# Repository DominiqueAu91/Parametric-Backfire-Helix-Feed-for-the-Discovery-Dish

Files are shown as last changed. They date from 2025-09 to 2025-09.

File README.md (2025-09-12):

# Parametric Backfire Helix Feed for the Discovery Dish

**Goal.** A fully parametric **backfire helical feed** (single-wire) for deep prime-focus dishes (e.g., the **Discovery Dish**), supporting **circular polarization** (LHCP/RHCP), printable scaffolding, and an annular reflector (“donut”) sized for backfire operation. The design is plug-and-play with **Digitelektro’s ecosystem** (see third_party folder) and my extension tube that houses an **LNA + bias-T** directly behind the reflector to minimize system noise figure.

## Background & motivation

This started as a **radio-astronomy feed** around **1420 MHz** to detect Milky Way H I line. It quickly became a **parametric OpenSCAD model** and **3D-printable hardware** designed to be **plug-and-play** with **Digitelektro’s Discovery Dish** ecosystem and with an **extension tube** that shelters the **LNA** (plus bias-T) **in the reflector’s shadow**. Goals: switch L/S bands in minutes, **minimize overall NF** (LNA at the feed), and keep a **mechanically & RF-robust** setup for experimentation.

## What this model does

- **Backfire helix** scaffold + **annular reflector (“donut”)** sized for backfire (default inner diameter ≈ **0.29·λ**).
- **Dish reflection flips circular polarization**; set feed LH/RH accordingly (feed LHCP → sky RHCP, and vice-versa).
- **Parametric OpenSCAD**: frequency, turns, pitch angle (default **14°**), handedness, donut diameters, and vertical stiffening gussets.
- **Helix channel preview** (red) mirrors the subtracted volume for easy wire routing during assembly.

## Quick theory

- λ = c / f
- Circumference C ≈ k·λ (use k ≈ 1 for backfire) → D = k·λ / π
- Pitch per turn from pitch angle α:  
  p = π·D·tan(α)  (default α = 14°)
- Donut inner diameter ≈ 0.29·λ

## Key OpenSCAD parameters

- `freq_MHz`, `turns`, `pitch_angle_deg` (14° default), `circ_factor_k` (1.00 default)
- `helix_right_handed` (`true` / `false`). Remember: **dishes flip circular polarization**.
- `reflector_inner_factor` (0.29 default → donut inner ≈ 0.29·λ)
- `reflector_outer_d_mm` or `reflector_outer_factor` for outer diameter
- `support_inset_mm` to make the posts bite inside the helix radius
- Gussets: vertical plates, flat top / sloped bottom; join at center (`gusset_*`)

## Presets

See **BANDS.md** for L/S-band presets (H I + Radio-astro, GNSS, HRIT/HRPT, TT&C, 13 cm Amateur, Globalstar).

## How many turns? (illumination vs f/D)

The optimal number of helix turns depends on the dish focal ratio (f/D).  
A dish with smaller f/D (deeper dish) requires a **wider beam** (fewer turns).  
A dish with larger f/D (shallower dish) requires a **narrower beam** (more turns).

### Practical rule
- Dish edge angle from focus:  
  `θ_edge = arctan(0.5 / (f/D))`  
- Choose the helix length (number of turns × pitch) so that the **pattern taper at θ_edge** is about **–10 to –13 dB**.  
  This balances aperture efficiency and noise contribution.

### Typical values (backfire helix, D ≈ λ, pitch angle ≈ 14°)
- f/D ≈ 0.30 → 3.5–4 turns  
- f/D ≈ 0.35 → ~3.0 turns (Discovery Dish)  
- f/D ≈ 0.40 → 2.8–3.2 turns  
- f/D ≈ 0.45–0.50 → 2.5–3 turns

### Hydrogen line example
At 1420.42 MHz (`λ ≈ 211 mm`):  
- Helix diameter `≈ 67.2 mm`  
- Pitch per turn `≈ 52.6 mm`  
- For f/D = 0.35 → **3.0 turns** → helix height ≈ 158 mm  
- Donut inner diameter ≈ `0.29·λ ≈ 61 mm`  

This setting gives a clean illumination of the dish, with proper edge taper for low-noise radio astronomy work.

### Choosing the number of turns based on your noise environment

The “optimal” number of turns is not only a function of dish f/D, but also of your RF environment:

- **Quiet rural site:**  
  Use **~3 turns**. The dish edge is illuminated at about –10 dB, which maximizes aperture efficiency.  
  Ground spillover is low in quiet sites, so you benefit from the extra effective aperture.

- **Urban or noisy suburban site:**  
  Consider **5–7 turns**. The beam narrows and under-illuminates the dish (edge taper ≈ –15 to –18 dB).  
  Although efficiency drops slightly, spillover from the ground and local RFI is strongly reduced.  
  The effective system noise temperature is lower, so overall SNR can actually improve.

👉 Rule of thumb:  
- For **radio astronomy, HRPT, or weak-signal work in rural areas** → ~3 turns.  
- For **general SDR satellite reception in noisy areas** → 5–7 turns.

## Matching (¼-wave transformer)

Typical backfire single-wire helix impedance: `Z_feed ≈ 120–150 Ω`.  
Use a **quarter-wave transformer** with characteristic impedance: Z_t = √(50 · Z_feed)

Example: if `Z_feed = 125 Ω` → `Z_t ≈ 79 Ω`.  

Implement with a λ/4 section of coax, twin-line, or microstrip near the feed point.  
Fine-tune by trimming the first fraction of a turn.  

## Printing & assembly

PETG ~20% infill; use the red helix preview to pre-check the wire path. Put the LNA right behind the reflector (shadowed), bias-T at the SDR. Keep unintended metal away from the donut edge; **0.29·λ** inner diameter is RF-critical.
## Additional Files and Quick Start

Alongside the parametric OpenSCAD sources, two key design files are provided:

- **`tripod_helix_donut.scad`**  
  Parametric model of the backfire helix feed support with tripod posts, gussets, and donut base.  
  Fully customizable: frequency, reflector diameter, number of turns, pitch angle, etc.  
  Designed to generate a mechanically robust feed suitable for use at the focal point of the Discovery Dish or other parabolic reflectors.

- **`para_extension_tube_inserts_M3.scad`**  
  Parametric design of the extension tube adapter.  
  This tube fits between **Digitelektro’s backfire_helix_adapter_for_discovery_dish** (see third_party folder) and the backfire helix feed.  
  Its purpose is to house and protect an LNA (e.g. **SPF5189Z**), filter (e.g. **Mini-Circuits VHF 1200+**) and a Bias-T immediately behind the helix reflector, in the geometric shadow of the reflector.  
  It supports Ruthex threaded inserts (M3 or M4), making it easy to switch between different feeds (L-band and S-band) while maintaining strong mechanical stability.

### Pre-generated STL Files

For convenience, **STL files are provided for the 1420.42 MHz hydrogen line (H I radio astronomy)** configuration.  
These can be directly printed — PETG recommended, ≥20% infill — to assemble a ready-to-use feed for neutral hydrogen observations.

### Quick Start

1. If your goal is **1420 MHz radio astronomy (hydrogen line)**:  
   - Print the supplied STL files directly.  
   - Mount the backfire helix feed on your Discovery Dish using the extension tube.  
   - Insert your LNA + Bias-T inside the tube.

2. If you want to explore **other bands**:  
   - Open `tripod_helix_donut.scad` in OpenSCAD.  
   - Adjust parameters (frequency, turns, reflector diameter, polarization).  
   - Export your own STL for printing.  
   - Optional: use `para_extension_tube_inserts_M3.scad` if you need the protected LNA/Bias-T housing.

This makes the project **plug-and-play** for hydrogen line observations while still giving full flexibility for other L-band and S-band satellite experiments.
## Generating Gerber Files for Your Custom Reflector Disk

This project includes a KiCad 8 **action plugin** (`donut_reflector_disk_sma.py`) to generate a parametric round reflector PCB with:

- **Circular Edge.Cuts outline**  
- **Ground planes (F.Cu & B.Cu)** tied to the SMA ground pins  
- **Optional soldermask opening** (bare copper reflector)  
- **Centered "China 6x6 inner 4mm" or "CONSMA001-C-G" SMA footprint** (square or round GND pads)  
- **Custom silkscreen label**

### Steps to Generate Gerbers

1. **Run the plugin**  
   - In KiCad PCB Editor:  
     `Tools → External Plugins → Parametric Reflector Disk + SMA`  
   - Enter:
     - Frequency in MHz (auto-calculates reflector diameter = 0.29·λ)  
     - Custom silkscreen label  
     - Option: open soldermask (bare copper)  

2. **Verify in PCB Editor**  
   - Confirm the reflector disk outline is present.  
   - Ensure the copper zones fill properly and connect to the SMA ground pins.  
   - Use the **Highlight Net** tool: selecting any SMA ground pin should highlight the whole disk.

3. **Generate Gerbers**  
   - Go to: `File → Plot…`  
   - Choose **Gerber** format.  
   - Enable at least these layers:
     - `F.Cu`, `B.Cu`  
     - `F.Mask`, `B.Mask`  
     - `F.SilkS` (optional, for label)  
     - `Edge.Cuts` (always required)  
   - Click **Plot**.

4. **Generate Drill Files**  
   - In the same dialog, click **Generate Drill Files…**  
   - Select **Excellon format** and include **PTH drills**.  
   - Click **Generate Drill File**.

5. **Check with Gerber Viewer**  
   - Open the output in KiCad’s **GerbView**.  
   - Confirm:
     - Copper fills are present on both sides.  
     - Mask opening (if enabled) exposes the reflector area.  
     - Drill holes are correct for the SMA center pin and ground legs.  

6. **Prepare for Fabrication**  
   - Zip the Gerber and drill files.  
   - Upload to your fab (e.g., JLCPCB).  
   - Recommended JLCPCB options:
     - Material: FR-4, 1.6 mm  
     - Copper: 1 oz  
     - Surface finish: ENIG (1U")  
     - Soldermask: Black (or your choice)  
     - Silkscreen: White  

---

👉 With this workflow you can generate **custom reflector disks** for any band (L-band, S-band, hydrogen line at 1420 MHz, etc.) simply by entering the frequency in the plugin dialog.

## Licensing & credits

- This repo (OpenSCAD + plugin + docs): **CC0**
- Digitelektro / BackfireHelix: **GPL-3.0** — keep attribution & GPL if you reuse their PCB files.
- Classic backfire references: **Nakano & Yamauchi (IEEE)**, **W1GHZ**, **N1BWT** notes.

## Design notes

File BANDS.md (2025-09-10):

# Bands & presets (k = 1.00, pitch angle = 14°)
| Target band | f (MHz) | λ (mm) | Helix D (mm) | Pitch/turn (mm) | Donut inner ≈ 0.29·λ (mm) |
|---|---:|---:|---:|---:|---:|
| H I line | 1420.42 | 211.1 | 67.2 | 52.6 | 61.2 |
| Radio-astro L | 1520.00 | 197.37 | 62.82 | 49.21 | 57.24 |
| GNSS L1 | 1575.42 | 190.43 | 60.61 | 47.48 | 55.22 |
| HRIT/HRPT | 1694.10 | 177.09 | 56.37 | 44.15 | 51.35 |
| TT&C S-band | 2200.00 | 136.36 | 43.41 | 33.99 | 39.55 |
| Amateur 13 cm | 2400.00 | 125.00 | 39.79 | 31.17 | 36.25 |
| Globalstar downlink | 2484.00 | 120.77 | 38.44 | 30.11 | 35.02 |

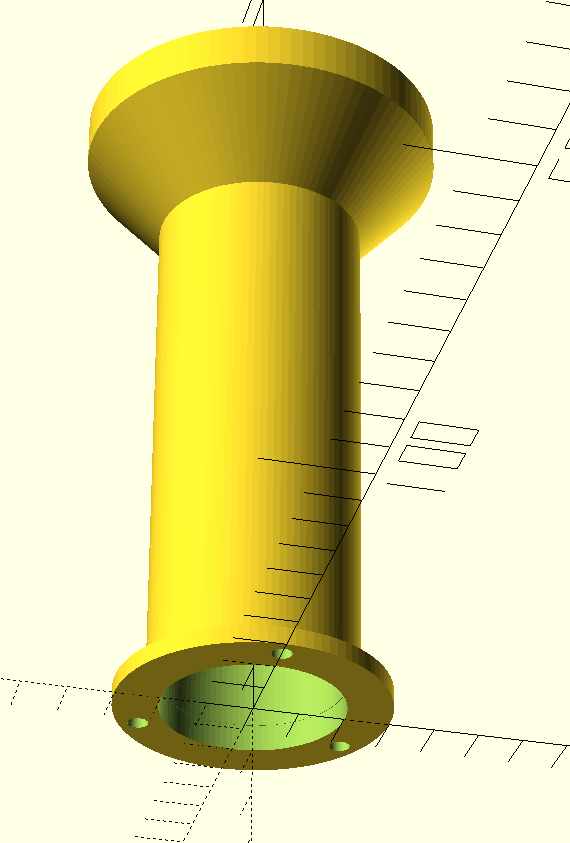
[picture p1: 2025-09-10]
Images/extension_tube_insert_1420.PNG

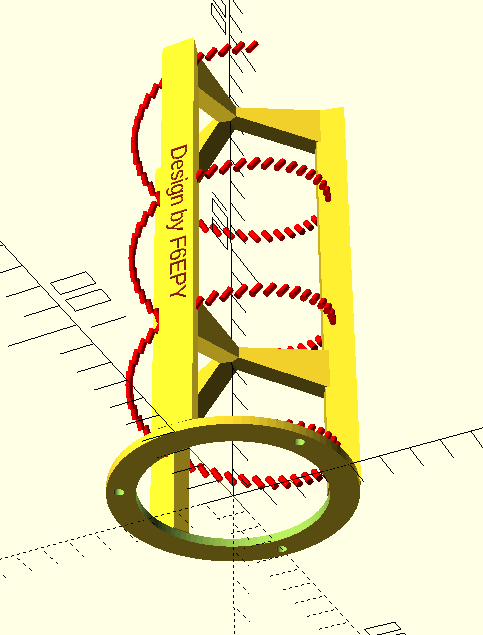
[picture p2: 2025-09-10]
Images/Backfire Helix.PNG

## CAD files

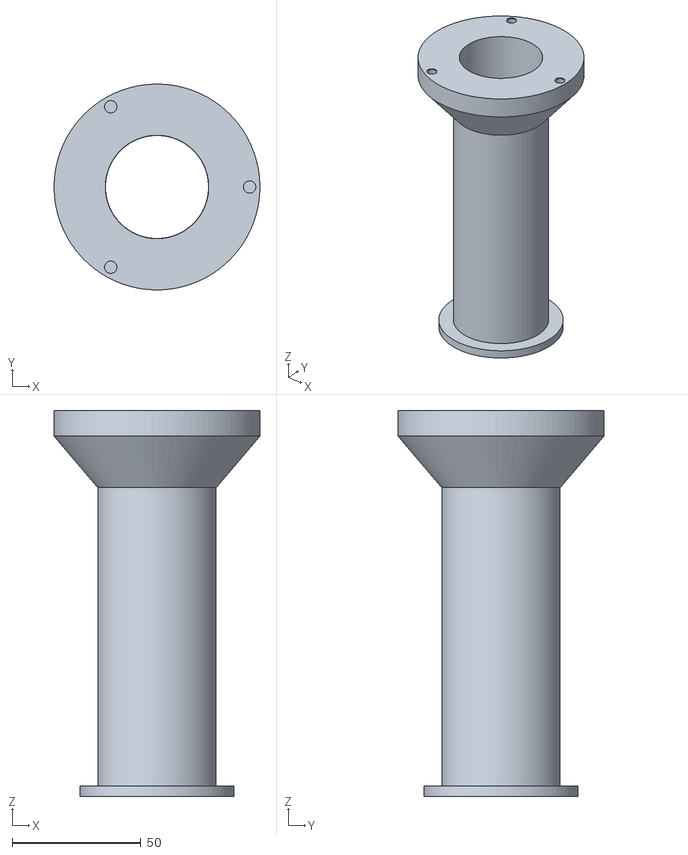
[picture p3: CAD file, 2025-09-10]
STL files/extension_tube_insert_M3_1420.stl
80.0 x 80.0 x 150.0

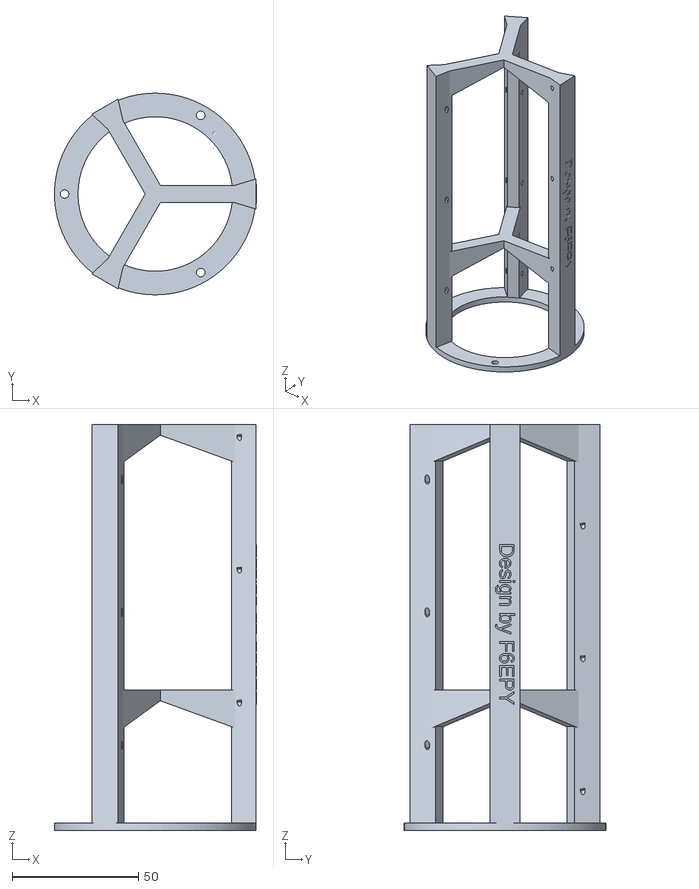
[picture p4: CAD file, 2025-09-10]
STL files/tripod_helix_donut_1420_H_I.stl
80.2 x 80.0 x 161.0

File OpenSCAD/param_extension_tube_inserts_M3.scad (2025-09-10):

//
// Parametric extension tube between Digitelektro's "Discovery Dish helix adapter"
// and "Backfire helix feed" to fit an LNA + Bias-T.
// Flange B: heat-set inserts ONLY (select M3 or M4). Clean & printable.
// Author: Cooperation between ChatGPT and Dominique F6EPY
// License: CC0

$fn = 96;

// ------------------------- User Parameters -------------------------

// Core tube
length_mm        = 120;   // extension length
id_mm            = 40;   // inner diameter
wall_mm          = 3;    // wall thickness
center_hole_A_d  = 40;   // central through-hole on flange A (Discovery side)
center_hole_B_d  = 40;   // central through-hole on flange B (Backfire side)
bevel_mm         = 0.6;  // small bevel on tube edges

// Flanges (A = Discovery side, B = Backfire side)
flangeA = [
  "thickness",   4,
  "outer_d",     60,
  "hole_count",  3,
  "bcd",         51.5,
  "hole_d",      4.5,   // A-side through holes
  "angle0_deg",  0,
  // optional features (set 0 to disable)
  "cbore_d",     7.5, "cbore_depth", 1.5,   // counterbore on OUTER face
  "boss_d",      42,  "boss_h",       1.0,  // boss (male) on INNER face
  "recess_d",     0,  "recess_h",     0     // recess (female) on INNER face
];

flangeB = [
  "thickness",   30,   // thicker, typically the tapered one
  "outer_d",     80,
  "hole_count",  3,
  "bcd",         72.0,
  "hole_d",      3.2,  // unused now (kept for compatibility)
  "angle0_deg",  0,
  // optional features
  "cbore_d",     0,   "cbore_depth", 0,
  "boss_d",      0,   "boss_h",      0,
  "recess_d",    42,  "recess_h",    1.0
];

// ---- Inserts on flange B ----
// Choose size M3/M4 (defaults below) OR override custom values
insert_size         = "M3";   // "M3" | "M4"
insert_override     = false;  // true -> use custom values below (ignoring size defaults)
insert_d_outer_M3   = 4.8;    // typical pocket Ø for Ruthex M3 in PLA/PETG
insert_len_M3       = 5.0;    // pocket depth for M3
insert_d_outer_M4   = 5.6;    // typical pocket Ø for Ruthex M4 in PLA/PETG
insert_len_M4       = 9.0;    // pocket depth for M4
insertB_d_outer     = 6.0;    // custom pocket Ø if override=true
insertB_length      = 6.0;    // custom pocket depth if override=true
insertB_chamfer     = 0.4;    // small entry chamfer height (mm)

// Taper setup — applies to ONE side only (kept as before)
tapered_flange     = "B";   // "A" or "B"
taper_enabled      = true;  // set false to disable taper entirely
big_at_outer       = true;  // true: big OD at OUTER face; false: big OD at INNER face
taper_flat_side    = "big"; // keep a flat at "big" or "small" OD side
taper_flat_h       = 10;    // default flat height (mm)
taper_flat_B_h     = 10;    // specific flat height for flange B (overrides default)

// ------------------------- Helpers -------------------------

function kv(h, k, default_val=0) =
    let (idx = search([k], [for(i=[0:len(h)/2-1]) h[2*i]]))
    (len(idx) > 0) ? h[2*idx[0]+1] : default_val;

function is_tapered(which) =
    (taper_enabled && ((tapered_flange == "A" && which=="A") || (tapered_flange == "B" && which=="B")));

function ins_d_default(size) = (size=="M3") ? insert_d_outer_M3 : insert_d_outer_M4;
function ins_h_default(size) = (size=="M3") ? insert_len_M3     : insert_len_M4;

module bevel_ring(id, od, h) {
  difference() {
    cylinder(h=h, d=od, center=false);
    translate([0,0,-0.01]) cylinder(h=h+0.02, d=id, center=false);
  }
}

module cbore(d, depth) { translate([0,0,-depth]) cylinder(h=depth, d=d, center=false); }

// ------------------------- Main geometry -------------------------

module adapter_tube() {
  tube_od = id_mm + 2*wall_mm;

  union() {
    // Tube
    difference() {
      cylinder(h=length_mm, d=tube_od, center=false);
      translate([0,0,-0.01]) cylinder(h=length_mm+0.02, d=id_mm, center=false);
    }
    if (bevel_mm > 0) {
      translate([0,0,0]) bevel_ring(id_mm, tube_od, bevel_mm);
      translate([0,0,length_mm]) rotate([180,0,0]) bevel_ring(id_mm, tube_od, bevel_mm);
    }

    // Flanges
    translate([0,0,0])         flange_end(flangeA, "A");           // inner face at Z=0
    translate([0,0,length_mm]) flange_end(flangeB, "B");           // inner face at Z=0 of this module
  }
}

module flange_end(params, which="A") {
  tube_od   = id_mm + 2*wall_mm;

  th        = kv(params,"thickness",4);
  od        = kv(params,"outer_d", tube_od + 10);
  hole_cnt  = kv(params,"hole_count",0);
  bcd       = kv(params,"bcd",0);
  hole_d    = kv(params,"hole_d",3.2);
  angle0    = kv(params,"angle0_deg",0);

  cbore_d     = kv(params,"cbore_d",0);
  cbore_depth = kv(params,"cbore_depth",0);
  boss_d      = kv(params,"boss_d",0);
  boss_h      = kv(params,"boss_h",0);
  recess_d    = kv(params,"recess_d",0);
  recess_h    = kv(params,"recess_h",0);

  // Resolve insert dimensions by size/override (used only if which=="B")
  ins_d  = insert_override ? insertB_d_outer : ins_d_default(insert_size);
  ins_h  = insert_override ? insertB_length  : ins_h_default(insert_size);

  difference() {
    // ---- BODY (core + outer skin) ----
    union() {
      // Core: keeps inner bore unchanged
      cylinder(h=th, d=tube_od, center=false);

      if (is_tapered(which)) {
        flat_h = min((which=="B" ? taper_flat_B_h : taper_flat_h), th);

        // Inner face is Z=0, outer face is Z=th.
        big_at_z   = big_at_outer ? th : 0;   // where OD = od
        small_at_z = big_at_outer ? 0  : th;  // where OD = tube_od

        if (taper_flat_side == "big") {
          if (big_at_z == 0) {
            // Flat z=0..flat_h at OD=od
            difference() {
              cylinder(h=flat_h, d=od, center=false);
              translate([0,0,-0.01]) cylinder(h=flat_h+0.02, d=tube_od, center=false);
            }
            if (th > flat_h) translate([0,0,flat_h]) difference() {
              cylinder(h=th-flat_h, d1=od, d2=tube_od, center=false);
              translate([0,0,-0.01]) cylinder(h=th-flat_h+0.02, d=tube_od, center=false);
            }
          } else {
            if (th > flat_h) difference() {
              cylinder(h=th-flat_h, d1=tube_od, d2=od, center=false);
              translate([0,0,-0.01]) cylinder(h=th-flat_h+0.02, d=tube_od, center=false);
            }
            translate([0,0,th-flat_h]) difference() {
              cylinder(h=flat_h, d=od, center=false);
              translate([0,0,-0.01]) cylinder(h=flat_h+0.02, d=tube_od, center=false);
            }
          }
        } else { // flat on "small" side
          if (small_at_z == 0) {
            if (th > flat_h) translate([0,0,flat_h]) difference() {
              cylinder(h=th-flat_h, d1=tube_od, d2=od, center=false);
              translate([0,0,-0.01]) cylinder(h=th-flat_h+0.02, d=tube_od, center=false);
            }
          } else {
            if (th > flat_h) difference() {
              cylinder(h=th-flat_h, d1=od, d2=tube_od, center=false);
              translate([0,0,-0.01]) cylinder(h=th-flat_h+0.02, d=tube_od, center=false);
            }
            // top flat implicit by core
          }
        }
      } else {
        // Non-tapered outer cylinder at OD + tiny shoulder to tube OD
        cylinder(h=th, d=od, center=false);
        shoulder_h = max(0.01, min(1.2, th*0.25));
        cylinder(h=shoulder_h, d=tube_od, center=false);
      }
    }

    // ---- SUBTRACTIONS ----

    // Flange A: bolt circle (traversant classique)
    if (which=="A" && hole_cnt > 0 && bcd > 0) {
      for (i=[0:hole_cnt-1]) {
        ang = angle0 + 360*i/hole_cnt;
        px = (bcd/2)*cos(ang);
        py = (bcd/2)*sin(ang);
        translate([px, py, 0]) cylinder(h=th+0.4, d=hole_d, center=false);
      }
    }

    // Flange B: inserts (M3/M4) — blind pockets on OUTER flat
    if (which=="B" && hole_cnt > 0 && bcd > 0) {
      depth = min(ins_h, th-0.4);
      for (i=[0:hole_cnt-1]) {
        ang = angle0 + 360*i/hole_cnt;
        px = (bcd/2)*cos(ang);
        py = (bcd/2)*sin(ang);
        if (depth > 0) {
          translate([px, py, th - depth]) cylinder(h=depth+0.2, d=ins_d, center=false);
          if (insertB_chamfer > 0 && insertB_chamfer < depth)
            translate([px, py, th - insertB_chamfer])
              cylinder(h=insertB_chamfer+0.2, d1=ins_d+0.6, d2=ins_d, center=false);
        }
      }
    }

    // Central through-hole (per flange)
    chd = (which=="A") ? center_hole_A_d : center_hole_B_d;
    translate([0,0,-1]) cylinder(h=th+2, d=chd, center=false);
    translate([0,0,-1]) cylinder(h=th+2, d=chd+0.2, center=false);

    // Female recess on inner face (optional)
    if (recess_d > 0 && recess_h > 0)
      translate([0,0,0]) cylinder(h=recess_h, d=recess_d, center=false);
  }
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

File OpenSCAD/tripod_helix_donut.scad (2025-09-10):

//
// Backfire Helix Tripod + Donut (parametric)
// - Donut: inner = 0.29·λ by default (backfire), outer set by factor or mm
// - Helix: pitch angle (default 14°), C = k·λ, RH/LH handedness
// - Vertical gussets: flat top, sloped bottom; join at center; printable slopes
// - Subtractive helix channel + (optional) red preview
// Author: Dominique F6EPY + ChatGPT — CC0
//

// --- engraving config ---
engrave_enable            = true;
engrave_text              = "Design by F6EPY";
engrave_support_angle     = 0;       // 0 / 120 / 240
engrave_size_mm           = 6;
engrave_depth_mm          = 1.8;     // must be > face_gap
engrave_pos_frac          = 0.50;    // 0..1 along height
engrave_face_gap          = 0.15;    // small air gap before wall
engrave_use_tangential    = false;   // true = side (+/-Y), false = radial (+/-X)
engrave_outer_face        = true;    // tangential: +Y outer / radial: +X outer(back)
engrave_y_frac            = 0.0;     // -0.5..+0.5 across width (radial mode)
engrave_text_rot_deg      = 0;       // rotate text on face
engrave_debug_cube        = false;    // notch first to verify
engrave_overlay_show      = true;    // draw red overlay (F5) if desired
engrave_flip_horizontal = true;   // flip text horizontally to correct mirroring


// --- preview controls ---
preview_mode        = 2;     // 0=subtractive, 1=transparent overlay, 2=subtractive+red-peek, 3=cutaway
structure_alpha     = 0.35;  // transparency for overlay mode (mode 1)
preview_expand_mm   = 0.30;  // extra radius for red preview (mode 2)

// Cutaway settings (mode 3)
cutaway_axis        = "X";   // "X","Y","Z"
cutaway_offset_mm   = 0;     // shift cut plane along axis
cutaway_keep_positive = true;// keep +axis side (true) or –axis side (false)

// ---------- Quality / robustness ----------
$fn_solid   = 96;    // donuts/supports/gussets
$fn_channel = 28;    // helix channel cylinders (keep lower)
eps_z       = 0.02;  // tiny Z nudge to avoid coplanar faces

// ---------- RF & helix ----------
freq_MHz           = 1420;
turns              = 3.0;
circ_factor_k      = 1.00;   // C = k*lambda (≈1 for backfire)
pitch_angle_deg    = 14;     // degrees (OpenSCAD trig uses degrees)
helix_right_handed = true;   // true = RH, false = LH
helix_phase0_deg   = 45;

// ---------- Donut (annular reflector) ----------
reflector_inner_factor = 0.29; // inner ≈ 0.29*lambda
reflector_outer_d_mm   = 80;    // if 0 => use factor below
reflector_outer_factor = 0.90; // outer ≈ 0.90*lambda when outer_d_mm==0
base_thick             = 3;

// ---------- Bolt circle (optional) ----------
bolt_hole_count   = 3;
bolt_circle_d     = 72;
bolt_hole_d       = 3.5;
bolt_angle0_deg   = 60;

// ---------- Supports (trapezoids) ----------
support_inset_mm     = 3.5;  // posts bite inside helix radius
support_w_outer      = 12;   // tangential width near donut
support_w_inner      = 6;    // tangential width near center
support_outer_margin = 0;    // setback from donut outer radius

// ---------- Vertical gussets (radial planes) ----------
gusset_enable        = true;
gusset_top_h         = 0;   // flat top height above donut
gusset_center_thick  = 3.5;  // vertical thickness at center (min)
gusset_post_thick    = 15.0;  // vertical thickness at support (target)
gusset_angle_max_deg = 45;   // max printable slope (degrees)
gusset_embed_rad     = 1.5;  // radial embed into support
gusset_min_tan       = 2.8;  // min tangential extrusion width
levels_per_rev       = 2.0;    // gusset rings per full turn (>=1)
show_gusset_debug    = false;

// ---------- Helix channel (subtractive) + preview ----------
wire_d             = 1.4;
wire_clearance     = 0.6;
helix_step_deg     = 8;      // 6..10 typical; larger = lighter
show_helix_preview = true;
helix_preview_alpha= 1.0;
helix_preview_d    = 0;      // 0 => same as channel_d

// ---------- Debug ----------
show_axis          = false;

// ---------- Helpers ----------
function clamp(x,a,b) = (x < a) ? a : ((x > b) ? b : x);

// ---------- Derived ----------
lambda  = 300.0 / (freq_MHz/1000.0);
circum  = circ_factor_k * lambda;
helix_D = circum / PI;
helix_R = helix_D/2;
pitch   = PI * helix_D * tan(pitch_angle_deg);  // degrees OK in OpenSCAD
H_total = turns * pitch;

reflector_ir = (reflector_inner_factor * lambda) / 2;
reflector_or = (reflector_outer_d_mm > 0) ? (reflector_outer_d_mm/2)
                                          : ((reflector_outer_factor*lambda)/2);

// global radii for supports/gussets
post_inner_r = max(helix_R - support_inset_mm, 0.1);
post_outer_r = max(reflector_ir + 3, reflector_or - support_outer_margin);

// tangential width of support vs radius (linear interpolation)
function support_width_at(r) =
    (abs(post_outer_r - post_inner_r) < 1e-6)
    ? support_w_inner
    : let(t = clamp((r - post_inner_r) / (post_outer_r - post_inner_r), 0, 1))
      support_w_inner + t * (support_w_outer - support_w_inner);

// ---------- Modules ----------
module axis(len=80){
  color("red")   cube([len,0.8,0.8], center=true);
  color("green") cube([0.8,len,0.8], center=true);
  color("blue")  cube([0.8,0.8,len], center=true);
}

module reflector_donut(){
  difference(){
    cylinder(h=base_thick, r=reflector_or, center=false, $fn=$fn_solid);
    translate([0,0,-0.1])
      cylinder(h=base_thick+0.2, r=reflector_ir, center=false, $fn=$fn_solid);
    if (bolt_hole_count>0 && bolt_circle_d>0){
      for (i=[0:bolt_hole_count-1]){
        ang = bolt_angle0_deg + 360*i/bolt_hole_count;
        translate([ (bolt_circle_d/2)*cos(ang), (bolt_circle_d/2)*sin(ang), -0.1 ])
          cylinder(h=base_thick+0.2, d=bolt_hole_d, center=false, $fn=$fn_solid);
      }
    }
  }
}

module support_trapezoid(ang=0){
  r_in  = post_inner_r;
  r_out = post_outer_r;

  // trapezoid in XY before rotation
  p1x = r_in;  p1y = +support_w_inner/2;
  p2x = r_in;  p2y = -support_w_inner/2;
  p3x = r_out; p3y = -support_w_outer/2;
  p4x = r_out; p4y = +support_w_outer/2;

  c = cos(ang); s = sin(ang);
  P1 = [ p1x*c - p1y*s, p1x*s + p1y*c ];
  P2 = [ p2x*c - p2y*s, p2x*s + p2y*c ];
  P3 = [ p3x*c - p3y*s, p3x*s + p3y*c ];
  P4 = [ p4x*c - p4y*s, p4x*s + p4y*c ];

  // nudge up by eps_z so it's not coplanar with donut
  translate([0,0,base_thick + eps_z])
    linear_extrude(height=H_total)
      polygon(points=[ P1, P2, P3, P4 ]);
}

module tripod_supports(){
  support_trapezoid(0);
  support_trapezoid(120);
  support_trapezoid(240);
}

// Cylinder between two points p1 -> p2 with radius r (no norm(), all local)
// --- helper: cylinder between two points (no norm(), no globals)
module seg_cyl(p1, p2, r){
  v = [ p2[0]-p1[0], p2[1]-p1[1], p2[2]-p1[2] ];
  h = sqrt(v[0]*v[0] + v[1]*v[1] + v[2]*v[2]);
  if (h > 1e-6){
    ang = acos(v[2]/h) * 180/PI;     // degrees
    ax  = [ -v[1], v[0], 0 ];        // rotation axis (z -> v)
    translate(p1)
      rotate(ang, ax)
        cylinder(h=h, r=r, center=false, $fn=$fn_channel);
  }
}

// one vertical gusset (radial plane at ang), base offset z0 above donut
// tangential width equals support width at contact radius
module gusset_vertical_one(ang=0, z0=0){
  if (gusset_enable){
    Lr = clamp(post_inner_r + gusset_embed_rad, post_inner_r, post_outer_r);

    // printable slope constraint (bottom drop limit across radial run Lr)
    max_drop = Lr * tan(gusset_angle_max_deg);

    // top edge (flat) — nudge by eps_z to avoid coplanar
    z_top = base_thick + eps_z + z0 + gusset_top_h;

    // desired vertical thicknesses
    t_center = gusset_center_thick;
    t_post   = gusset_post_thick;

    // bottoms (limit post side by slope)
    z_bot_center      = z_top - t_center;
    z_bot_post_target = z_top - t_post;
    z_bot_allowed_min = z_bot_center - max_drop;
    z_bot_post        = max(z_bot_post_target, z_bot_allowed_min);

    // 2D radial section (X,Z)
    pts = [
      [ 0,  z_bot_center ],
      [ 0,  z_top        ],
      [ Lr, z_top        ],
      [ Lr, z_bot_post   ]
    ];

    tan_width = max(gusset_min_tan, support_width_at(Lr));

    if (show_gusset_debug)
      color([1,0,0,0.5])
        rotate([0,0,ang])
          rotate([90,0,0])
            linear_extrude(height=tan_width, center=true, convexity=10)
              polygon(points=pts);
    else
      rotate([0,0,ang])
        rotate([90,0,0])
          linear_extrude(height=tan_width, center=true, convexity=10)
            polygon(points=pts);
  }
}

module gusset_vertical_triplet(z0=0){
  gusset_vertical_one(0,   z0);
  gusset_vertical_one(120, z0);
  gusset_vertical_one(240, z0);
}

module gussets_vertical_all(){
  if (gusset_enable){
    max_t = floor(turns);
    stepN = (levels_per_rev < 1) ? 1 : levels_per_rev;
    for (t = [1 : stepN : max_t]){
      z0 = t * pitch;
      gusset_vertical_triplet(z0);
    }
  }
}
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

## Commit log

2025-09-10 Rename extension_tube_insert_M3_1420.stl to STL files/extension_tube_insert_M3_1420.stl
    [extension_tube_insert_M3_1420.stl]
2025-09-10 Rename tripod_helix_donut_1420_H_I.stl to STL files/tripod_helix_donut_1420_H_I.stl
    [tripod_helix_donut_1420_H_I.stl]
2025-09-11 Rename backfire_helix_adapter_for_discovery_dish (1).STL to third_party/backfire_helix_adapter_for_discovery_dish.STL
